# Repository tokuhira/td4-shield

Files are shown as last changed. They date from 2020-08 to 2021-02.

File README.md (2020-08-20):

# td4-shield

「CPUの創りかた」に則ったちょっと最近のプロジェクトです。

# Photo

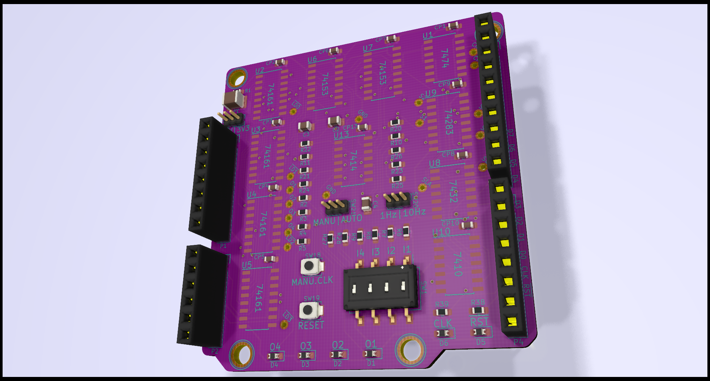
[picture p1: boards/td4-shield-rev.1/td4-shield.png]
実際にはまだ製造していないrev.1の想像図 3d_view


# Features

書籍に記載の内容を少しアレンジしての製作例です。
汎用ロジックICはSOICにしています。
ROMと電源はArduinoで代用するため、UNO用のShieldとして使います。
コードはArduino全般で動作することを目標としつつも、メインターゲットはSTM32です。

# Requirement

Arduino互換のボードが別途必要です。

# Installation

色々やり方はありますが、Arduino UNOに差し込むのが簡単です。
ボードのIO電圧に合わせてJP1を設定します。

# Usage

各々方でご自由に実験していただけます。

# Note

可用性、安全性、その他いかなる性質も保証しません。
いかなる用法も、またのその結果も保証しません。

# Author

* @tokuhira (twitter)
* github.com/tokuhira

# License

BSD 3-Clause License

Copyright (c) 2020, tokuhira.net
All rights reserved.

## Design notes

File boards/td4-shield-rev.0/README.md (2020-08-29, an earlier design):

# td4-shield-rev.0

「CPUの創りかた」を読んで実験するための野良基板の試作版です。

# Photo

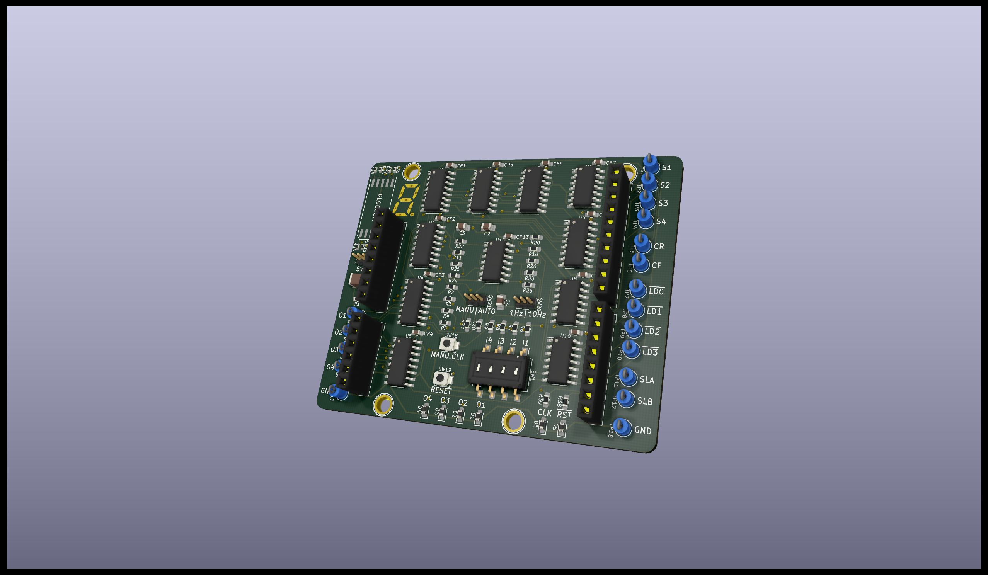
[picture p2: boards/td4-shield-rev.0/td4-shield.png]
試作版rev.0の3D図 3d_view

試作版rev.0の実装例 impl_shot

# Resouces

- [回路図](td4-shield-rev.0_sch.pdf)
- [部品表](td4-shield-rev.0_parts.pdf)
- [ブース](https://tokuhira.booth.pm/items/2313677)

# Features

書籍に記載の内容を少しアレンジしての製作例です。
汎用ロジックICはSOICにしています。
ROMと電源はArduinoで代用するため、UNO用Shieldとして使います。
試作版の例に違わず設計不良を含んでいます。
U2、U3、U4、U5への配線で、1番と2番のピンが逆になっています。

# Requirement

この回路のままでは動作しませんので、パターンカットと追加配線が必要です。
Arduino互換のボードと、そのマイコンで動作するROMエミュレータプログラムが別途必要です。
色々と実験する場合はオシロスコープやロジックアナライザがあると便利だと思います。

# Installation

色々やり方はありますが、Arduino UNOに差し込むのが簡単です。
ボードのIO電圧に合わせてJP1を設定します。

# Usage

各々方でご自由に実験していただけます。

# Note

可用性、安全性、その他いかなる性質も保証しません。
いかなる用法も、またのその結果も保証しません。

# Author

* @tokuhira (twitter)
* github.com/tokuhira

# License

BSD 3-Clause License

Copyright (c) 2020, tokuhira.net
All rights reserved.

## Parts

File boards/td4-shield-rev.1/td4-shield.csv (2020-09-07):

Comment | Designator | Footprint | LCSC
100uF 16V | C1 | Capacitor_SMD:C_1210_3225Metric_Pad1.42x2.65mm_HandSolder
10uF 16V | C2,C3,C4 | Capacitor_SMD:C_0805_2012Metric_Pad1.15x1.40mm_HandSolder
0.1uF | CP1,CP2,CP3,CP4,CP5,CP6,CP7,CP8,CP9,CP10,CP13 | Capacitor_SMD:C_0603_1608Metric_Pad1.05x0.95mm_HandSolder
LED | D1,D2,D3,D4,D5,D6 | Diode_SMD:D_0603_1608Metric_Pad1.05x0.95mm_HandSolder
VCC:+5V/+3V3 | JP1 | Connector_PinHeader_1.27mm:PinHeader_1x03_P1.27mm_Vertical
Power | P1 | Socket_Arduino_Uno:Socket_Strip_Arduino_1x08
Analog | P2 | Socket_Arduino_Uno:Socket_Strip_Arduino_1x06
Digital | P3 | Socket_Arduino_Uno:Socket_Strip_Arduino_1x10
Digital | P4 | Socket_Arduino_Uno:Socket_Strip_Arduino_1x08
CONN_01X01 | P5,P6,P7,P8 | Socket_Arduino_Uno:Arduino_1pin
DNP | R1 | Resistor_SMD:R_0603_1608Metric_Pad1.05x0.95mm_HandSolder
10K | R20 | Resistor_SMD:R_0603_1608Metric_Pad1.05x0.95mm_HandSolder
100K | R21,R22,R23,R24 | Resistor_SMD:R_0603_1608Metric_Pad1.05x0.95mm_HandSolder
3.3K | R25 | Resistor_SMD:R_0603_1608Metric_Pad1.05x0.95mm_HandSolder
33K | R26 | Resistor_SMD:R_0603_1608Metric_Pad1.05x0.95mm_HandSolder
100 | R27,R28 | Resistor_SMD:R_0603_1608Metric_Pad1.05x0.95mm_HandSolder
1K | R2,R3,R4,R5,R6,R7,R8,R9,R10,R11,R38,R39 | Resistor_SMD:R_0603_1608Metric_Pad1.05x0.95mm_HandSolder
INPUT | SW1 | Button_Switch_SMD:SW_DIP_SPSTx04_Slide_Omron_A6S-410x_W8.9mm_P2.54mm
Manual Clock | SW18 | Button_Switch_SMD:SW_SPST_B3U-1000P-B
Reset | SW19 | Button_Switch_SMD:SW_SPST_B3U-1000P-B
CLK:10Hz/1Hz | SW20 | Connector_PinHeader_1.27mm:PinHeader_1x03_P1.27mm_Vertical
CLK:NOR/MAN | SW21 | Connector_PinHeader_1.27mm:PinHeader_1x03_P1.27mm_Vertical
S1 | TP1 | Measurement_Points:Measurement_Point_Round-TH_Small
LD3 | TP10 | Measurement_Points:Measurement_Point_Round-TH_Small
SLA | TP11 | Measurement_Points:Measurement_Point_Round-TH_Small
SLB | TP12 | Measurement_Points:Measurement_Point_Round-TH_Small
O1 | TP13 | Measurement_Points:Measurement_Point_Round-TH_Small
O2 | TP14 | Measurement_Points:Measurement_Point_Round-TH_Small
O3 | TP15 | Measurement_Points:Measurement_Point_Round-TH_Small
O4 | TP16 | Measurement_Points:Measurement_Point_Round-TH_Small
GND | TP17,TP18 | Measurement_Points:Measurement_Point_Round-TH_Small
S2 | TP2 | Measurement_Points:Measurement_Point_Round-TH_Small
S3 | TP3 | Measurement_Points:Measurement_Point_Round-TH_Small
S4 | TP4 | Measurement_Points:Measurement_Point_Round-TH_Small
CR | TP5 | Measurement_Points:Measurement_Point_Round-TH_Small
CF | TP6 | Measurement_Points:Measurement_Point_Round-TH_Small
LD0 | TP7 | Measurement_Points:Measurement_Point_Round-TH_Small
LD1 | TP8 | Measurement_Points:Measurement_Point_Round-TH_Small
LD2 | TP9 | Measurement_Points:Measurement_Point_Round-TH_Small
74HC74 | U1 | Housings_SOIC:SOIC-14_3.9x8.7mm_Pitch1.27mm
74HC10 | U10 | Housings_SOIC:SOIC-14_3.9x8.7mm_Pitch1.27mm
74HC14 | U13 | Housings_SOIC:SOIC-14_3.9x8.7mm_Pitch1.27mm
74HC161 | U2,U3,U4,U5 | Housings_SOIC:SOIC-16_3.9x9.9mm_Pitch1.27mm
74HC153 | U6,U7 | Housings_SOIC:SOIC-16_3.9x9.9mm_Pitch1.27mm
74HC32 | U8 | Housings_SOIC:SOIC-14_3.9x8.7mm_Pitch1.27mm
74HC283 | U9 | Housings_SOIC:SOIC-16_3.9x9.9mm_Pitch1.27mm

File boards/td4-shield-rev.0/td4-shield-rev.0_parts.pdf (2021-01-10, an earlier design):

td4-shield-rev.0_parts.xlsx

Mounted
Designator | Part Detail | Qty | LCSC Part No.
C2,C3,C4 | Multilayer Ceramic Capacitors MLCC - SMD/SMT 10uF 25V 0805 RoHS | 3 | C15850
CP1,CP2,CP3,CP4,CP5,CP6,CP7,CP8,CP9,CP10, CP13 | Multilayer Ceramic Capacitors MLCC - SMD/SMT 100nF 50V 0603 RoHS | 11 | C14663
D1,D2,D3,D4,D5,D6 | Light Emitting Diodes (LED) Blue 465~475nm 11.5~28.5mcd@5mA Top View 0603 RoHS | 6 | C72041
R2,R3,R4,R5,R6,R7,R8,R9,R10,R11,R38,R39 | Chip Resistor - Surface Mount 1KOhms ±1% 1/10W 0603 RoHS | 12 | C21190
R20 | Chip Resistor - Surface Mount 10KOhms ±1% 1/10W 0603 RoHS | 1 | C25804
R21,R22,R23,R24 | Chip Resistor - Surface Mount 100KOhms ±1% 1/10W 0603 RoHS | 4 | C25803
R25 | Chip Resistor - Surface Mount 3.3KOhms ±1% 1/10W 0603 RoHS | 1 | C22978
R26 | Chip Resistor - Surface Mount 33KOhms ±1% 1/10W 0603 RoHS | 1 | C4216
R27,R28 | Chip Resistor - Surface Mount 100Ohms ±1% 1/10W 0603 RoHS | 2 | C22775
R30,R31,R32,R33,R34,R35,R36,R37 | Chip Resistor - Surface Mount 1KOhms ±1% 1/16W 0402 RoHS | 8 | C11702

Optional Parts
Designator | Part Detail | Qty | Other Part No.
C1 | CAP CER 100UF 16V X5R 1210 | 1 | EMK325ABJ107MM-T
SW18,SW19 | SWITCH TACTILE SPST-NO 0.05A 12V | 2 | B3U-1000P-B
SW1 | SWITCH SLIDE DIP SPST 25MA 24V | 1 | A6S-4104-H
U1 | IC FF D-TYPE DUAL 1BIT 14SOIC | 1 | SN74HC74DR
U2,U3,U4,U5 | IC 4BIT SYNC BINRY COUNTR 16SOIC | 4 | SN74HC161DR
U6,U7 | IC MULTIPLEXER 2 X 4:1 16SOIC | 2 | SN74HC153DR
U8 | IC GATE OR 4CH 2-INP 14SOIC | 1 | CD74HC32M96
U9 | IC 4BIT BINARY FULL ADDER 16SOIC | 1 | CD74HC283M96
U10 | IC GATE NAND 3CH 3-INP 14SOIC | 1 | SN74HC10DR
U13 | IC INVERTER SCHMITT 6CH 14SOIC | 1 | CD74HC14M96

Not Included
Designator | Part Detail | Qty | Comment
JP1,SW20,SW21 | Connector_PinHeader_1.27mm:PinHeader_1x03_P1.27mm_Vertical | 3 | Select switch
P1,P4 | Socket_Arduino_Uno:Socket_Strip_Arduino_1x08 | 2 | As you like
P2 | Socket_Arduino_Uno:Socket_Strip_Arduino_1x06 | 1 | As you like
P3 | Socket_Arduino_Uno:Socket_Strip_Arduino_1x10 | 1 | As you like
R1 | Chip Resistor - Surface Mount 1KOhms ±1% 1/16W 0402 RoHS | 1 | DNP
TP1,TP2,TP3,TP4,TP5,TP6,TP7,TP8,TP9,TP10,T P11,TP12,TP13,TP14,TP15,TP16,TP17,TP18 | Measurement_Points:Measurement_Point_Round-TH_Small | 18 | As you like
U14 | GL9D03M - Surface Mount Type Numeric LED | 1 | As you like

2021-01-10

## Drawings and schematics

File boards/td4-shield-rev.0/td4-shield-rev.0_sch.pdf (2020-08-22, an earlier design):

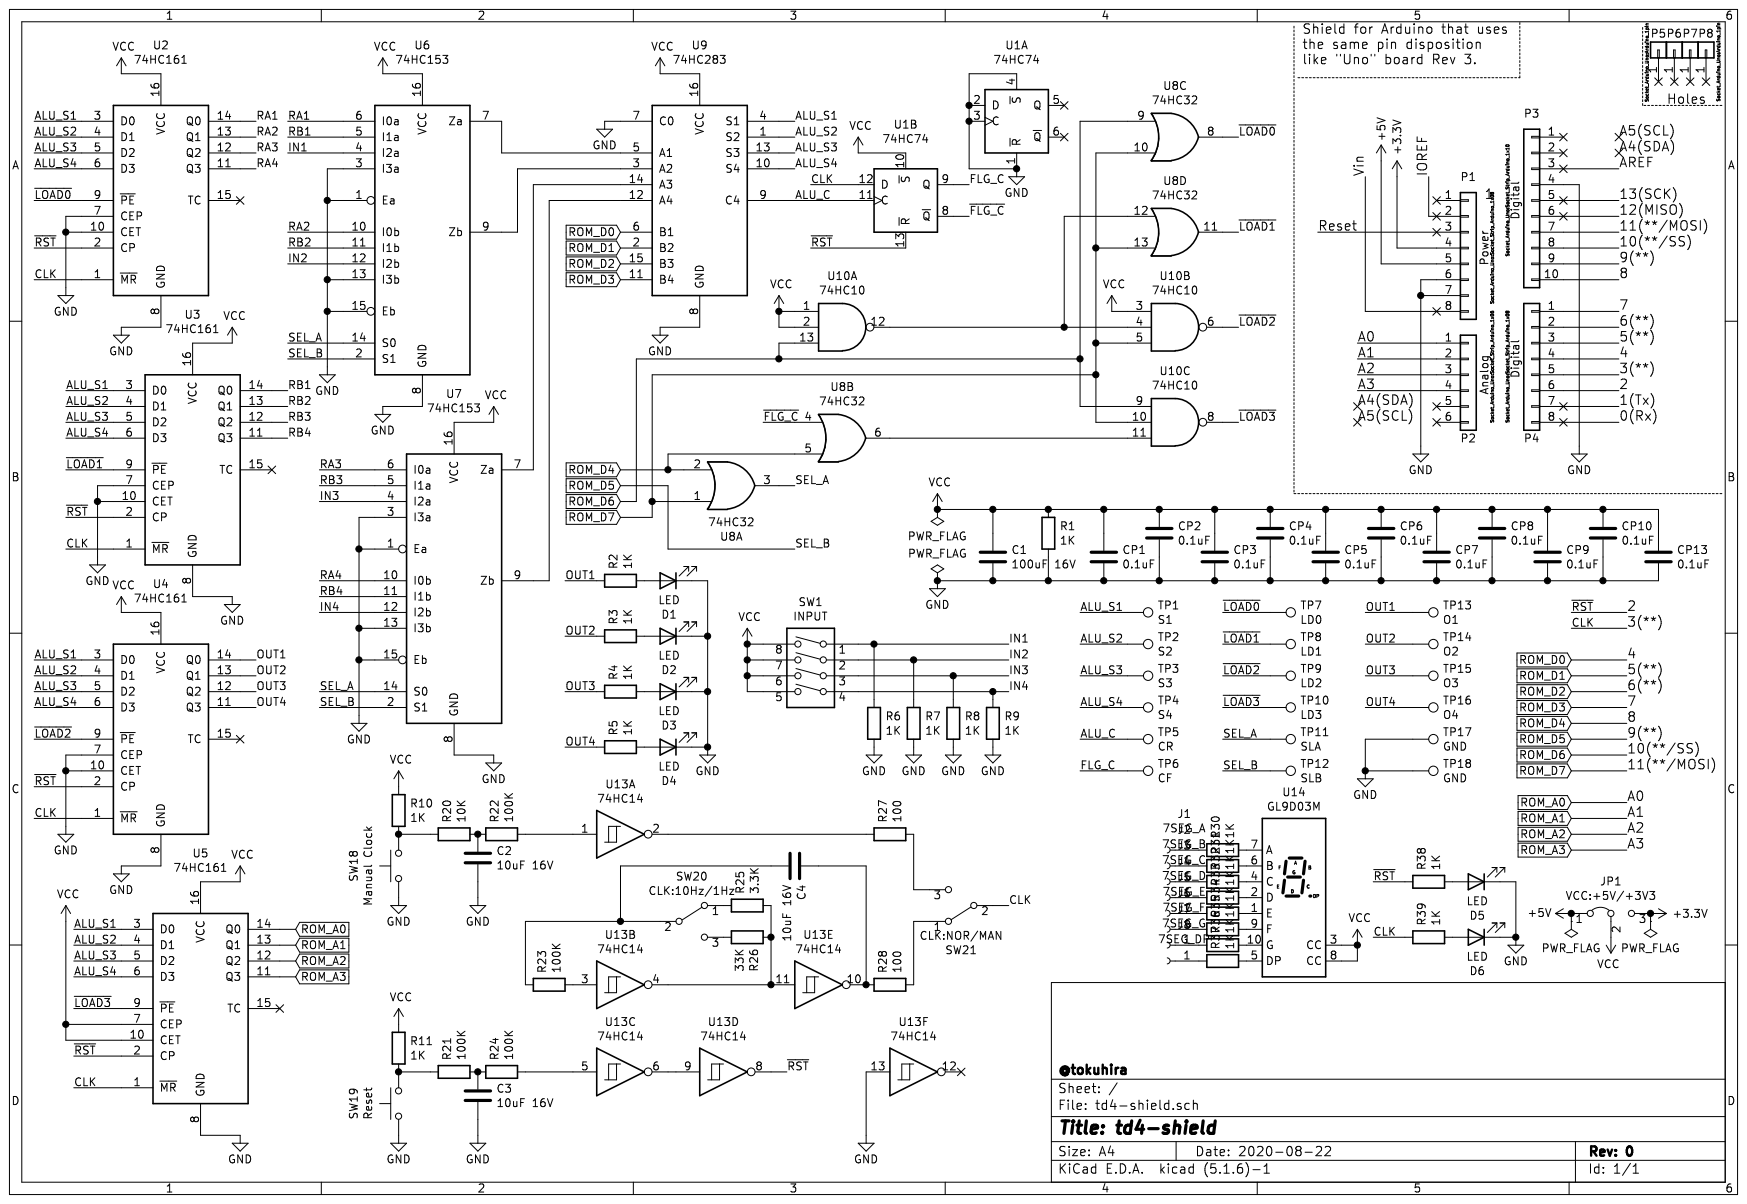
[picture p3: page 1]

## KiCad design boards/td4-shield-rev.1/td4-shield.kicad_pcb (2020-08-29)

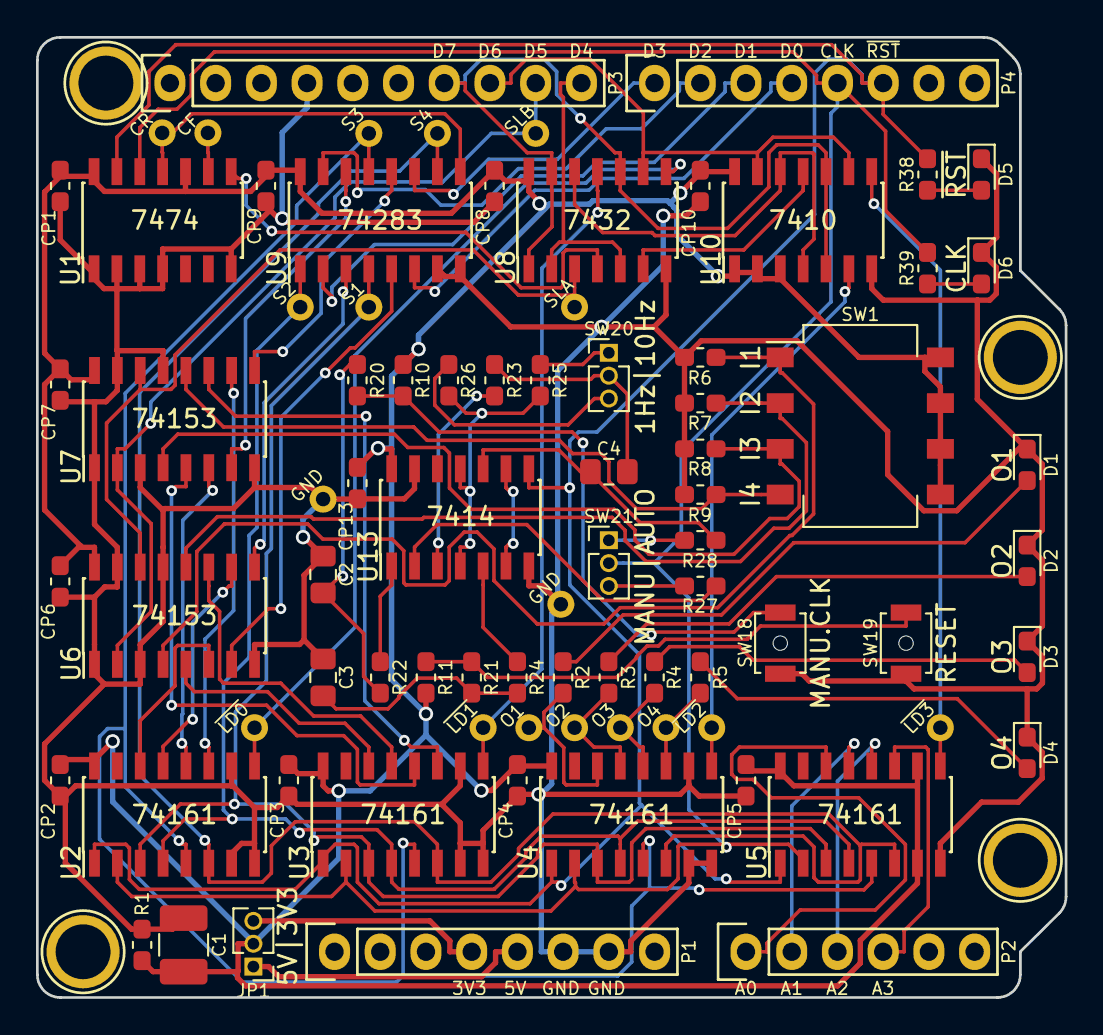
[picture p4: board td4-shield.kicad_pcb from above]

Board: 2 copper layers, 57.2 x 53.3 mm, 87 parts (1 on the bottom side), 74 nets.

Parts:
C1: 100uF 16V; C_1210_3225Metric_Pad1.42x2.65mm_HandSolder
C2, C3, C4: 10uF 16V; C_0805_2012Metric_Pad1.15x1.40mm_HandSolder
CP1, CP2, CP3, CP4, CP5, CP6, CP7, CP8, CP9, CP10, CP13: 0.1uF; C_0603_1608Metric_Pad1.05x0.95mm_HandSolder
D1, D2, D3, D4, D5, D6: LED; D_0603_1608Metric_Pad1.05x0.95mm_HandSolder
JP1: VCC:+5V/+3V3; PinHeader_1x03_P1.27mm_Vertical
LOGO1: OSHW-Logo2_9.8x8mm_SilkScreen
P1: Power; Socket_Strip_Arduino_1x08
P2: Analog; Socket_Strip_Arduino_1x06
P3: Digital; Socket_Strip_Arduino_1x10
P4: Digital; Socket_Strip_Arduino_1x08
P5, P6, P7, P8: CONN_01X01; Arduino_1pin
R1: DNP; R_0603_1608Metric_Pad1.05x0.95mm_HandSolder
R2, R3, R4, R5, R6, R7, R8, R9, R10, R11, R38, R39: 1K; R_0603_1608Metric_Pad1.05x0.95mm_HandSolder
R20: 10K; R_0603_1608Metric_Pad1.05x0.95mm_HandSolder
R21, R22, R23, R24: 100K; R_0603_1608Metric_Pad1.05x0.95mm_HandSolder
R25: 3.3K; R_0603_1608Metric_Pad1.05x0.95mm_HandSolder
R26: 33K; R_0603_1608Metric_Pad1.05x0.95mm_HandSolder
R27, R28: 100; R_0603_1608Metric_Pad1.05x0.95mm_HandSolder
SW1: INPUT; SW_DIP_SPSTx04_Slide_Omron_A6S-410x_W8.9mm_P2.54mm
SW18: Manual Clock; SW_SPST_B3U-1000P-B
SW19: Reset; SW_SPST_B3U-1000P-B
SW20: CLK:10Hz/1Hz; PinHeader_1x03_P1.27mm_Vertical
SW21: CLK:NOR/MAN; PinHeader_1x03_P1.27mm_Vertical
TP1: S1; Measurement_Point_Round-TH_Small
TP2: S2; Measurement_Point_Round-TH_Small
TP3: S3; Measurement_Point_Round-TH_Small
TP4: S4; Measurement_Point_Round-TH_Small
TP5: CR; Measurement_Point_Round-TH_Small
TP6: CF; Measurement_Point_Round-TH_Small
TP7: LD0; Measurement_Point_Round-TH_Small
TP8: LD1; Measurement_Point_Round-TH_Small
TP9: LD2; Measurement_Point_Round-TH_Small
TP10: LD3; Measurement_Point_Round-TH_Small
TP11: SLA; Measurement_Point_Round-TH_Small
TP12: SLB; Measurement_Point_Round-TH_Small
TP13: O1; Measurement_Point_Round-TH_Small
TP14: O2; Measurement_Point_Round-TH_Small
TP15: O3; Measurement_Point_Round-TH_Small
TP16: O4; Measurement_Point_Round-TH_Small
TP17, TP18: GND; Measurement_Point_Round-TH_Small
U1: 74HC74; SOIC-14_3.9x8.7mm_Pitch1.27mm
U2, U3, U4, U5: 74HC161; SOIC-16_3.9x9.9mm_Pitch1.27mm
U6, U7: 74HC153; SOIC-16_3.9x9.9mm_Pitch1.27mm
U8: 74HC32; SOIC-14_3.9x8.7mm_Pitch1.27mm
U9: 74HC283; SOIC-16_3.9x9.9mm_Pitch1.27mm
U10: 74HC10; SOIC-14_3.9x8.7mm_Pitch1.27mm
U13: 74HC14; SOIC-14_3.9x8.7mm_Pitch1.27mm

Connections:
+3V3: JP1.3, P1.4
+5V: JP1.1, P1.5
/2: P4.6, R38.1, U1.13, U2.1, U3.1, U4.1, U5.1, U13.8
/3(**): P4.5, R39.1, SW21.2, U1.12, U2.2, U3.2, U4.2, U5.2
/ALU_C: TP5.1, U1.11, U9.9
/ALU_S1: TP1.1, U2.3, U3.3, U4.3, U5.3, U9.4
/ALU_S2: TP2.1, U2.4, U3.4, U4.4, U5.4, U9.1
/ALU_S3: TP3.1, U2.5, U3.5, U4.5, U5.5, U9.13
/ALU_S4: TP4.1, U2.6, U3.6, U4.6, U5.6, U9.10
/FLG_C: TP6.1, U1.9
/IN1: R6.1, SW1.1, U6.4
/IN2: R7.1, SW1.2, U6.12
/IN3: R8.1, SW1.3, U7.4
/IN4: R9.1, SW1.4, U7.12
/OUT1: R2.1, TP13.1, U4.14
/OUT2: R3.1, TP14.1, U4.13
/OUT3: R4.1, TP15.1, U4.12
/OUT4: R5.1, TP16.1, U4.11
/RA1: U2.14, U6.6
/RA2: U2.13, U6.10
/RA3: U2.12, U7.6
/RA4: U2.11, U7.10
/RB1: U3.14, U6.5
/RB2: U3.13, U6.11
/RB3: U3.12, U7.5
/RB4: U3.11, U7.11
/SEL_A: TP11.1, U6.14, U7.14, U8.3
/~FLG_C: U1.8, U8.4
/~LOAD0: TP7.1, U2.9, U8.8
/~LOAD1: TP8.1, U3.9, U8.11
/~LOAD2: TP9.1, U4.9, U10.6
/~LOAD3: TP10.1, U5.9, U10.8
GND: C1.2, C2.2, C3.2, CP1.2, CP2.2, CP3.2, CP4.2, CP5.2, CP6.2, CP7.2, CP8.2, CP9.2, CP10.2, CP13.2, D1.1, D2.1, D3.1, D4.1, D5.1, D6.1, P1.6, P1.7, P3.4, R1.2, R6.2, R7.2, R8.2, R9.2, SW18.1, SW19.1, TP17.1, TP18.1, U1.1, U1.2, U1.3, U1.4, U1.7, U2.7, U2.8, U2.10, U3.7, U3.8, U3.10, U4.7, U4.8, U4.10, U5.8, U6.1, U6.3, U6.8, U6.13, U6.15, U7.1, U7.3, U7.8, U7.13, U7.15, U8.7, U9.7, U9.8, U10.7, U13.7, U13.13
unnamed: C2.1, R20.2, R22.1
unnamed: C3.1, R21.2, R24.1
unnamed: C4.1, R28.1, U13.10
unnamed: C4.2, R23.1, SW20.2
unnamed: D1.2, R2.2
unnamed: D2.2, R3.2
unnamed: D3.2, R4.2
unnamed: D4.2, R5.2
unnamed: D5.2, R38.2
unnamed: D6.2, R39.2
unnamed: R10.2, R20.1, SW18.2
unnamed: R11.2, R21.1, SW19.2
unnamed: R22.2, U13.1
unnamed: R23.2, U13.3
unnamed: R24.2, U13.5
unnamed: R25.1, SW20.1
unnamed: R25.2, R26.1, U13.4, U13.11
unnamed: R26.2, SW20.3
unnamed: R27.1, U13.2
unnamed: R27.2, SW21.3
unnamed: R28.2, SW21.1
unnamed: U6.7, U9.5
unnamed: U6.9, U9.3
unnamed: U7.7, U9.14
unnamed: U7.9, U9.12
unnamed: U8.6, U10.11
unnamed: U8.12, U10.4, U10.12
unnamed: U13.6, U13.9
ROM_A0: P2.1, U5.14
ROM_A1: P2.2, U5.13
ROM_A2: P2.3, U5.12
ROM_A3: P2.4, U5.11
ROM_D0: P4.4, U9.6
ROM_D1: P4.3, U9.2
ROM_D2: P4.2, U9.15
ROM_D3: P4.1, U9.11
ROM_D4: P3.10, U8.2, U8.5
ROM_D5: P3.9, TP12.1, U6.2, U7.2
ROM_D6: P3.8, U8.9, U10.9, U10.13
ROM_D7: P3.7, U8.1, U8.10, U8.13, U10.5, U10.10
VCC: C1.1, CP1.1, CP2.1, CP3.1, CP4.1, CP5.1, CP6.1, CP7.1, CP8.1, CP9.1, CP10.1, CP13.1, JP1.2, R1.1, R10.1, R11.1, SW1.5, SW1.6, SW1.7, SW1.8, U1.10, U1.14, U2.16, U3.16, U4.16, U5.7, U5.10, U5.16, U6.16, U7.16, U8.14, U9.16, U10.1, U10.2, U10.3, U10.14, U13.14

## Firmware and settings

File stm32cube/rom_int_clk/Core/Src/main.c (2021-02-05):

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
/* Includes ------------------------------------------------------------------*/
#include "main.h"

/* USER CODE BEGIN Includes */
#include <string.h>
#include "td4_rom.h"
#include "PCA9624.h"

/* USER CODE END Includes */

/* USER CODE BEGIN PTD */
typedef uint8_t seg7[7];

/* USER CODE END PTD */

/* USER CODE BEGIN PD */
#define ROM_BASE_ADDRESS    0
#define ROM_DEFAULT_ADDRESS 0

#define I2C_RETRIES         2
#define I2C_TIMEOUT         2

#define LED_PWM_FULL        0xff // PWM = 99.6%
#define LED_PWM_OFF         0    // PWM = 0%
/* USER CODE END PD */

I2C_HandleTypeDef hi2c1;

UART_HandleTypeDef huart2;

/* USER CODE BEGIN PV */
volatile int ticked = 0;
volatile int led_ok = 0;
uint8_t cmd[32];
seg7 hex2seg7[] = { // 0xff は PWM で 99.6% 出力
  { 0xff, 0xff, 0xff, 0xff, 0xff, 0xff, 0x00 }, // 0
  { 0x00, 0xff, 0xff, 0x00, 0x00, 0x00, 0x00 }, // 1
  { 0xff, 0xff, 0x00, 0xff, 0xff, 0x00, 0xff }, // 2
  { 0xff, 0xff, 0xff, 0xff, 0x00, 0x00, 0xff }, // 3
  { 0x00, 0xff, 0xff, 0x00, 0x00, 0xff, 0xff }, // 4
  { 0xff, 0x00, 0xff, 0xff, 0x00, 0xff, 0xff }, // 5
  { 0xff, 0x00, 0xff, 0xff, 0xff, 0xff, 0xff }, // 6
  { 0xff, 0xff, 0xff, 0x00, 0x00, 0x00, 0x00 }, // 7
  { 0xff, 0xff, 0xff, 0xff, 0xff, 0xff, 0xff }, // 8
  { 0xff, 0xff, 0xff, 0xff, 0x00, 0xff, 0xff }, // 9
  { 0xff, 0xff, 0xff, 0xff, 0xff, 0x00, 0xff }, // a
  { 0x00, 0x00, 0xff, 0xff, 0xff, 0xff, 0xff }, // b
  { 0x00, 0x00, 0x00, 0xff, 0xff, 0x00, 0xff }, // c
  { 0x00, 0xff, 0xff, 0xff, 0xff, 0x00, 0xff }, // d
  { 0xff, 0xff, 0x00, 0xff, 0xff, 0xff, 0xff }, // e
  { 0xff, 0x00, 0x00, 0x00, 0xff, 0xff, 0xff }, // f
};

/* USER CODE END PV */

void SystemClock_Config(void);
static void MX_GPIO_Init(void);
static void MX_USART2_UART_Init(void);
static void MX_I2C1_Init(void);
/**
  * @brief  The application entry point.
  * @retval int
  */
int main(void)
{
  /* USER CODE BEGIN 1 */
  HAL_StatusTypeDef ret;

  /* USER CODE END 1 */

  /* MCU Configuration--------------------------------------------------------*/

  /* Reset of all peripherals, Initializes the Flash interface and the Systick. */
  HAL_Init();

  /* Configure the system clock */
  SystemClock_Config();

  /* Initialize all configured peripherals */
  MX_GPIO_Init();
  MX_USART2_UART_Init();
  MX_I2C1_Init();
  /* USER CODE BEGIN 2 */

  /* PCA9624 */
  ret = HAL_I2C_IsDeviceReady(&hi2c1, PCA9624_ADDR, I2C_RETRIES, I2C_TIMEOUT);
  if (ret == HAL_OK) // PCA9624 から ACK を受信
  {
    cmd[0] = MODE1; // モードレジスタ
    cmd[1] = 0x0;   // SLEEP = 0 で低消費電力モードを解除して通常動作へ
    ret = HAL_I2C_Master_Transmit(&hi2c1, PCA9624_ADDR, cmd, 2, HAL_MAX_DELAY);
    if (ret == HAL_OK)
    {
      cmd[0] = LEDOUT0 + 0x80; // LEDOUT0 オートインクリメント
      cmd[1] = 0xaa;           // LED3,2,1,0 各々の2ビットに 0b10 で PWM点灯を指定
      cmd[2] = 0xaa;           // LED7,6,5,4 各々の2ビットに 0b10 で PWM点灯を指定
      ret = HAL_I2C_Master_Transmit(&hi2c1, PCA9624_ADDR, cmd, 3, HAL_MAX_DELAY);
      if (ret == HAL_OK)
      {
        led_ok = 1; // PCA9624 の初期化完了
      }
    }
  }

  /* USER CODE END 2 */

  /* Infinite loop */
  /* USER CODE BEGIN WHILE */
  while (1)
  {
    static int address = ROM_DEFAULT_ADDRESS;
    /* USER CODE END WHILE */

    /* USER CODE BEGIN 3 */
    if (ticked)
    {
      /* Read demand address for ROM */
      address = ROM_BASE_ADDRESS;
      address += (HAL_GPIO_ReadPin(A0_GPIO_Port, A0_Pin) << 0);
      address += (HAL_GPIO_ReadPin(A1_GPIO_Port, A1_Pin) << 1);
      address += (HAL_GPIO_ReadPin(A2_GPIO_Port, A2_Pin) << 2);
      address += (HAL_GPIO_ReadPin(A3_GPIO_Port, A3_Pin) << 3);
      if (led_ok) // PCA9624
      {
        cmd[0] = PWM0 + 0x80;                  // PWM0 オートインクリメント
        memcpy(&cmd[1], hex2seg7[address], 7); // 7 セグメントの PWM 値を直接設定
        cmd[8] = LED_PWM_FULL;                 // DP は一旦点灯
        ret = HAL_I2C_Master_Transmit(&hi2c1, PCA9624_ADDR, cmd, 9, HAL_MAX_DELAY);
        if (ret != HAL_OK)
        {
          led_ok = 0; // PCA9624 でエラー発生
          // TODO: I2C のリカバリ処理をここで
        }
      }
      ticked = 0;
    }

    /* Update bits of ROM */
    HAL_GPIO_WritePin(D0_GPIO_Port, D0_Pin, rom[address] & 1 << 0);
    HAL_GPIO_WritePin(D1_GPIO_Port, D1_Pin, rom[address] & 1 << 1);
    HAL_GPIO_WritePin(D2_GPIO_Port, D2_Pin, rom[address] & 1 << 2);
    HAL_GPIO_WritePin(D3_GPIO_Port, D3_Pin, rom[address] & 1 << 3);
    HAL_GPIO_WritePin(D4_GPIO_Port, D4_Pin, rom[address] & 1 << 4);
    HAL_GPIO_WritePin(D5_GPIO_Port, D5_Pin, rom[address] & 1 << 5);
    HAL_GPIO_WritePin(D6_GPIO_Port, D6_Pin, rom[address] & 1 << 6);
    HAL_GPIO_WritePin(D7_GPIO_Port, D7_Pin, rom[address] & 1 << 7);
    if (led_ok) // PCA9624
    {
      HAL_Delay(50);        // ちょっとだけ待ってから
      cmd[0] = PWM7;        // DPを
      cmd[1] = LED_PWM_OFF; // 消灯
      ret = HAL_I2C_Master_Transmit(&hi2c1, PCA9624_ADDR, cmd, 2, HAL_MAX_DELAY);
      if (ret != HAL_OK)
      {
        led_ok = 0; // PCA9624 でエラー発生
        // TODO: I2C のリカバリ処理をここで
      }
    }
  }
  /* USER CODE END 3 */
}

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
/* USER CODE BEGIN 4 */
void HAL_GPIO_EXTI_Callback(uint16_t GPIO_Pin)
{
  if (GPIO_Pin == CLK_Pin)
  {
    ticked = 1;
  }
}

/* USER CODE END 4 */
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


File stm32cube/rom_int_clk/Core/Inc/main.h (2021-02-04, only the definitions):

#define B1_Pin GPIO_PIN_13
#define B1_GPIO_Port GPIOC
#define A0_Pin GPIO_PIN_0
#define A0_GPIO_Port GPIOA
#define A1_Pin GPIO_PIN_1
#define A1_GPIO_Port GPIOA
#define USART_TX_Pin GPIO_PIN_2
#define USART_TX_GPIO_Port GPIOA
#define USART_RX_Pin GPIO_PIN_3
#define USART_RX_GPIO_Port GPIOA
#define A2_Pin GPIO_PIN_4
#define A2_GPIO_Port GPIOA
#define LD2_Pin GPIO_PIN_5
#define LD2_GPIO_Port GPIOA
#define D7_Pin GPIO_PIN_7
#define D7_GPIO_Port GPIOA
#define A3_Pin GPIO_PIN_0
#define A3_GPIO_Port GPIOB
#define D2_Pin GPIO_PIN_10
#define D2_GPIO_Port GPIOB
#define D5_Pin GPIO_PIN_7
#define D5_GPIO_Port GPIOC
#define D3_Pin GPIO_PIN_8
#define D3_GPIO_Port GPIOA
#define D4_Pin GPIO_PIN_9
#define D4_GPIO_Port GPIOA
#define TMS_Pin GPIO_PIN_13
#define TMS_GPIO_Port GPIOA
#define TCK_Pin GPIO_PIN_14
#define TCK_GPIO_Port GPIOA
#define CLK_Pin GPIO_PIN_3
#define CLK_GPIO_Port GPIOB
#define CLK_EXTI_IRQn EXTI2_3_IRQn
#define D1_Pin GPIO_PIN_4
#define D1_GPIO_Port GPIOB
#define D0_Pin GPIO_PIN_5
#define D0_GPIO_Port GPIOB
#define D6_Pin GPIO_PIN_6
#define D6_GPIO_Port GPIOB

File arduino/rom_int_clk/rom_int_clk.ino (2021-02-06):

/**
   ROM emulator for TD4 using interrupt on CLK
*/
#include "td4_iface.h"
#include "td4_rom.h"

#define USE_PCA9624 // Drive 7 segments LED by PCA9624PW with program counter.

#ifdef USE_PCA9624
#include <Wire.h>
#include <string.h>
#include "pca9624.h"

typedef unsigned char seg7[7];
seg7 hex2seg7[] = { // 0xff means PWM output 99.6%
  { 0xff, 0xff, 0xff, 0xff, 0xff, 0xff, 0x00 }, // 0
  { 0x00, 0xff, 0xff, 0x00, 0x00, 0x00, 0x00 }, // 1
  { 0xff, 0xff, 0x00, 0xff, 0xff, 0x00, 0xff }, // 2
  { 0xff, 0xff, 0xff, 0xff, 0x00, 0x00, 0xff }, // 3
  { 0x00, 0xff, 0xff, 0x00, 0x00, 0xff, 0xff }, // 4
  { 0xff, 0x00, 0xff, 0xff, 0x00, 0xff, 0xff }, // 5
  { 0xff, 0x00, 0xff, 0xff, 0xff, 0xff, 0xff }, // 6
  { 0xff, 0xff, 0xff, 0x00, 0x00, 0x00, 0x00 }, // 7
  { 0xff, 0xff, 0xff, 0xff, 0xff, 0xff, 0xff }, // 8
  { 0xff, 0xff, 0xff, 0xff, 0x00, 0xff, 0xff }, // 9
  { 0xff, 0xff, 0xff, 0xff, 0xff, 0x00, 0xff }, // a
  { 0x00, 0x00, 0xff, 0xff, 0xff, 0xff, 0xff }, // b
  { 0x00, 0x00, 0x00, 0xff, 0xff, 0x00, 0xff }, // c
  { 0x00, 0xff, 0xff, 0xff, 0xff, 0x00, 0xff }, // d
  { 0xff, 0xff, 0x00, 0xff, 0xff, 0xff, 0xff }, // e
  { 0xff, 0x00, 0x00, 0x00, 0xff, 0xff, 0xff }, // f
};
#endif

const uint32_t clock_pin = CLK;
const uint32_t base_address = 0;
const uint32_t default_address = 0;

volatile int ticked = false;

void tick() {
  ticked = true;
}

#ifdef USE_PCA9624
uint8_t i2cWrite(char slave_address, unsigned char *cmd, int num) {
  Wire.beginTransmission(slave_address);
  for (int i = 0; i < num; i++) {
    Wire.write(*(cmd + i));
  }
  return Wire.endTransmission();
}

void writeSeg7(seg7 data) {
  unsigned char cmd[9];
  cmd[0] = PWM0 | 0x80;     // PWM0 + auto increment
  memcpy(&cmd[1], data, 7);
  cmd[8] = 0xff;            // Light on decimal point
  i2cWrite(PCA9624_ADDR, cmd, 9);
}

void writeSegDP(bool light) {
  unsigned char cmd[2];
  cmd[0] = PWM7;            // PWM7
  cmd[1] = light ? 0xff : 0x00;
  i2cWrite(PCA9624_ADDR, cmd, 2);
}

void initLEDdriver() {
  unsigned char cmd[3];

  cmd[0] = MODE1;           // MODE1
  cmd[1] = 0x00;            // SLEEP = 0
  i2cWrite(PCA9624_ADDR, cmd, 2);

  cmd[0] = LEDOUT0 | 0x80;  // LEDOUT0 + auto increment
  cmd[1] = 0xAA;            // LED 3, 2, 1, 0 : PWM(=10)
  cmd[2] = 0xAA;            // LED 7, 6, 5, 4 : PWM(=10)
  i2cWrite(PCA9624_ADDR, cmd, 3);
}
#endif

void setup() {
  for (uint32_t i = in_0; i < in_count; ++i) {
    pinMode(in_pins[i], INPUT);
  }
  for (uint32_t i = out_0; i < out_count; ++i) {
    pinMode(out_pins[i], OUTPUT);
  }
  attachInterrupt(digitalPinToInterrupt(clock_pin), tick, RISING);

#ifdef USE_PCA9624
  Wire.begin();
  initLEDdriver();
#endif
}

void loop() {
  static uint32_t address = default_address;

  if (ticked) {
    ticked = false;
    address = base_address;
    for (uint32_t i = in_0; i < in_count; ++i) {
      uint32_t bit = digitalRead(in_pins[i]);
      address += bit << i;
    }
#ifdef USE_PCA9624
    writeSeg7(hex2seg7[address]);
#endif
  }

  for (uint32_t i = out_0; i < out_count; ++i) {
    uint32_t bit = rom[address] >> i & 1;
    digitalWrite(out_pins[i], bit);
  }
#ifdef USE_PCA9624
  delay(50);
  writeSegDP(false);        // Light off decimal point
#endif
}

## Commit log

2020-08-19 Create td4-shield-rev.1 board
    [td4-shield-B_Cu.gbl, td4-shield-B_Mask.gbs, td4-shield-B_Paste.gbp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]
2020-08-20 Update kicad_pcb and gerber
    Silk modified.
    [td4-shield-B_Cu.gbl, td4-shield-B_Mask.gbs, td4-shield-B_Paste.gbp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]
2020-08-20 Update README.md
    Add 3d view image.
    [td4-shield.kicad_pcb]
2020-08-21 Update td4_iface.h
    Remove the dependency to STM32.
2020-08-22 Create stm32cube/rom_int_clk for NUCLEO-F030R8
2020-08-24 Update main.c of stm32cube/rom_int_clk
2020-08-27 Update td4-shield.sch
    Bug fix on sch, kicad_pcb has not been fixed yet!
    [td4-shield.sch]
2020-08-28 Fix the bugs on wiring to U2, U3, U4, and U5.
    [td4-shield-B_Cu.gbl, td4-shield-B_Mask.gbs, td4-shield-B_Paste.gbp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]
2020-09-07 Update td4-shield-rev.1
    Add BOM and positions.
    [td4-shield.csv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]
2020-09-08 Update gerber files
    [td4-shield-B_Cu.gbl, td4-shield-B_Mask.gbs, td4-shield-B_Paste.gbp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]
2021-02-04 Update codes with STM32CubeIDE
    STM32CubeIDE version: 1.4.2 -> 1.5.1
    FirmwarePackage: STM32Cube FW_F0 V1.11.0 -> STM32Cube FW_F0 V1.11.2
2021-02-04 Assign pins for I2C (PB8 and PB9)
2021-02-05 Update rom_int_clk with STM32CubeIDE
    Drive 7 segments LED by PCA9624PW with program counter.
2021-02-06 Update rom_int_clk with Adruino
    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
2021-05-21 Migrate to latest STM32CubeIDE
    STM32CubeIDE
    Version: 1.6.1
    Build: 9958_20210326_1446 (UTC)

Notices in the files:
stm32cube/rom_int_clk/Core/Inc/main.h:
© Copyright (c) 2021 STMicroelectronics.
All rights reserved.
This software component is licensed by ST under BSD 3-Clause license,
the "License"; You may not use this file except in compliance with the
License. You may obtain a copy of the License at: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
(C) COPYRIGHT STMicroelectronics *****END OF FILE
